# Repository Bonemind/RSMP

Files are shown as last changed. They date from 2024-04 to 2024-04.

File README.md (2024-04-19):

# RSMP

AKA "Rockstars Macropad". A [KMK](https://github.com/KMKfw/kmk_firmware) and Raspberry pi based 20 key macropad. The macropad is direct pin, meaning every button uses a dedication gpio pin, so no diodes are needed.

This was created for a workshop at [Team Rockstars IT](https://www.teamrockstars.nl/)

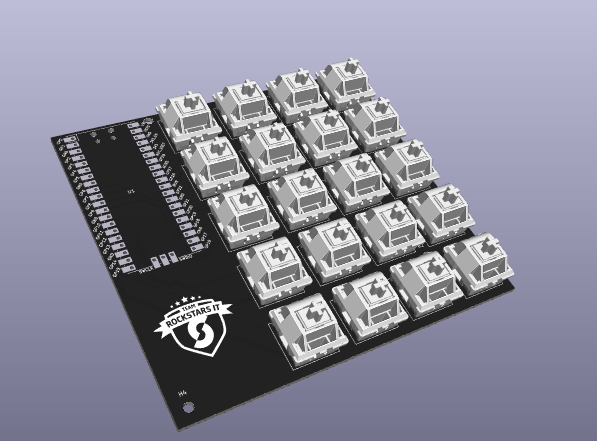
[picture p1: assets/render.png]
macropad render


## BOM

  - Raspberry Pi Pico. Make sure you get the variant with gpio pins 16/17 in the bottom right
  - 20 Cherry MX compatible switches
  - 20 Cherry MX keycaps
  - Main PCB
  - Bottom plate PCB
  - 8x M2.5 screws
  - 4 Spacers
  - Those round bumper things you stick under something to make it non-slip

## Software

  - Dowload the [Circuitpython](https://circuitpython.org/) release for the pico board.
  - Plug in the pi pico while holding the "boot" button
  - Copy the circuitpython Uf2 to the root of the device
  - It should now reboot, and you should have a "CIRCUITPY" storage device
  - Remove the `code.py` file from the storage device
  - Copy all files from the `firmware` folder to the root of the drive
  - Replug the device

It should now behave as a keyboard.

### Firmware

This macropad uses KMK for it's firmware. KMK is a flexible circuitpython based project for mechanical keyboards that offers a lot of options. The basic firmware for the RSMP is simple, in that every button outputs a letter. To customize the behavior, you can modify `main.py`.

As an example of layers, the bottom left button will output a space when tapped, and when held, the buttons will output numbers and various symbols instead of letters.

## Credits

  - [KMK](https://github.com/KMKfw/kmk_firmware) - Keyboard software
  - [ncarandini](https://github.com/ncarandini/KiCad-RP-Pico) - Kicad pi pico footprint and model
  - [foostan](https://github.com/foostan/kbd) - Keyboard switch footprints

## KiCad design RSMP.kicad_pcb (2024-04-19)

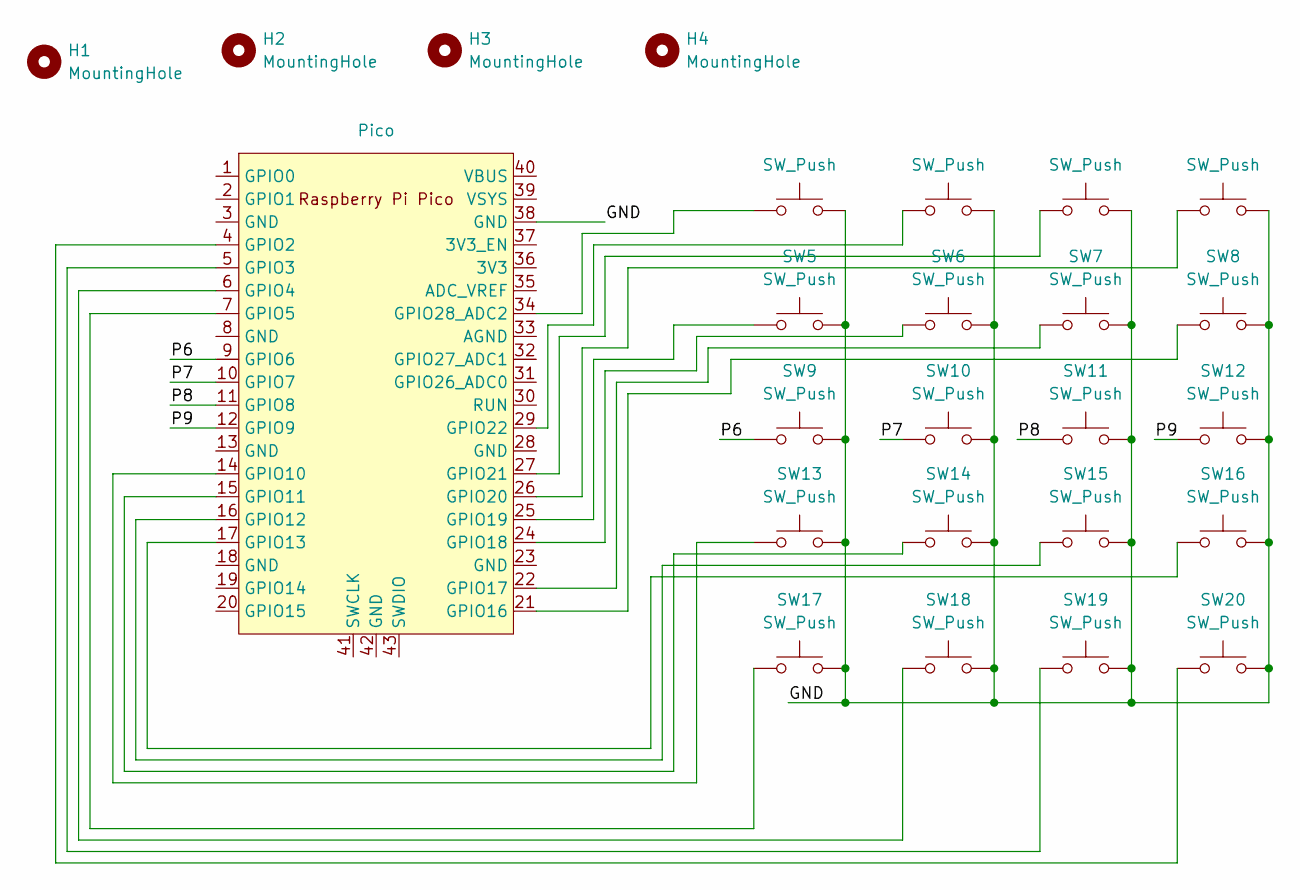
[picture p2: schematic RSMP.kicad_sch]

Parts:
H1, H2, H3, H4: MountingHole; MountingHole_2.7mm_M2.5
SW1, SW2, SW3, SW4, SW5, SW6, SW7, SW8, SW9, SW10, SW11, SW12, SW13, SW14, SW15, SW16, SW17, SW18, SW19, SW20: SW_Push; SW_Cherry_MX_1.00u_PCB
U1: Pico; RPi_Pico_SMD_TH

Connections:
/GND: SW1.2, SW2.2, SW3.2, SW4.2, SW5.2, SW6.2, SW7.2, SW8.2, SW9.2, SW10.2, SW11.2, SW12.2, SW13.2, SW14.2, SW15.2, SW16.2, SW17.2, SW18.2, SW19.2, SW20.2, U1.38 (GND)
/P6: SW9.1, U1.9 (GPIO6)
/P7: SW10.1, U1.10 (GPIO7)
/P8: SW11.1, U1.11 (GPIO8)
/P9: SW12.1, U1.12 (GPIO9)
unnamed: SW20.1, U1.4 (GPIO2)
unnamed: SW19.1, U1.5 (GPIO3)
unnamed: SW18.1, U1.6 (GPIO4)
unnamed: SW17.1, U1.7 (GPIO5)
unnamed: SW13.1, U1.14 (GPIO10)
unnamed: SW14.1, U1.15 (GPIO11)
unnamed: SW15.1, U1.16 (GPIO12)
unnamed: SW16.1, U1.17 (GPIO13)
unnamed: SW8.1, U1.21 (GPIO16)
unnamed: SW7.1, U1.22 (GPIO17)
unnamed: SW6.1, U1.24 (GPIO18)
unnamed: SW5.1, U1.25 (GPIO19)
unnamed: SW4.1, U1.26 (GPIO20)
unnamed: SW3.1, U1.27 (GPIO21)
unnamed: SW2.1, U1.29 (GPIO22)
unnamed: SW1.1, U1.34 (GPIO28_ADC2)

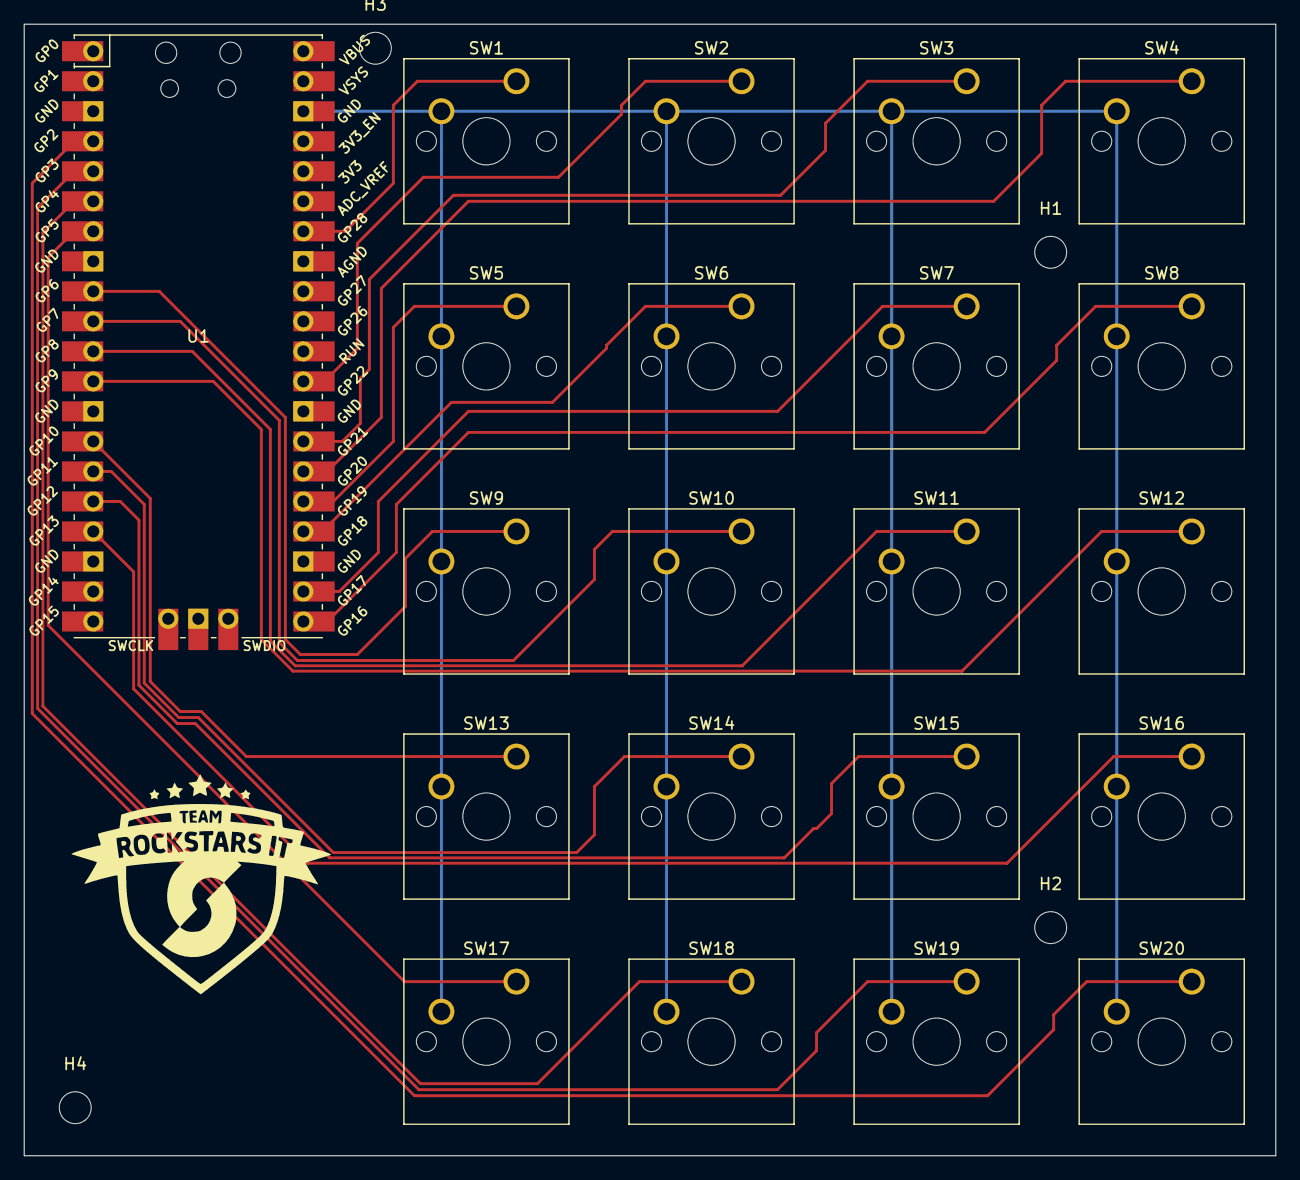
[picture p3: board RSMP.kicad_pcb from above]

Board: 2 copper layers, 105.9 x 95.8 mm, 25 parts (0 on the bottom side), 21 nets.

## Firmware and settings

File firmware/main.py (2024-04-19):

from kb import KMKKeyboard

from kmk.keys import KC
from kmk.modules.layers import Layers

keyboard = KMKKeyboard()
keyboard.tap_time = 100


layers = Layers()

layers_ext = Layers()
layers_ext.tap_time = 100

keyboard.modules = [layers_ext]
keyboard.extensions = []
#
# Cleaner key names
# _______ = KC.TRNS
# XXXXXXX = KC.NO

LAYER_ALT = 1
KCALT = KC.LT(LAYER_ALT, KC.SPC)

keyboard.keymap = [
    [  
        KC.A,    KC.B,    KC.C,    KC.D,
        KC.E,    KC.F,    KC.J,    KC.K,
        KC.L,    KC.M,    KC.N,    KC.O,
        KC.P,    KC.Q,    KC.R,    KC.S,
        KCALT,    KC.U,    KC.V,    KC.W,
    ],
    [  
        KC.N1,       KC.N2,       KC.N3,       KC.N4,
        KC.N5,       KC.N6,       KC.N7,       KC.N8,
        KC.N9,       KC.N0,       KC.LBRACKET, KC.RBRACKET,
        KC.QUOTE,    KC.COMMA,    KC.GRAVE,    KC.DOT,
        KC.SLASH,    KC.MINUS,    KC.EQUAL,    KC.ENTER,
    ],
]

if __name__ == '__main__':
    keyboard.go()

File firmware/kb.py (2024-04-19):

import board
import digitalio

from storage import getmount

from kmk.kmk_keyboard import KMKKeyboard as _KMKKeyboard
from kmk.scanners.keypad import KeysScanner

# GPIO to key mapping, Left
KEY_CFG = [
    board.GP28, board.GP22, board.GP21, board.GP20,
    board.GP19, board.GP18, board.GP17, board.GP16,
    board.GP6,  board.GP7,  board.GP8,  board.GP9,
    board.GP10, board.GP11, board.GP12, board.GP13,
    board.GP5,  board.GP4,  board.GP3,  board.GP2,
]

class KMKKeyboard(_KMKKeyboard):
    def __init__(self):
        # create and register the scanner
        self.matrix = KeysScanner(
            pins = KEY_CFG,
            value_when_pressed = False,	
            pull=True,
        )

    # flake8: noqa
    # fmt: off
    # coord_mapping = [
    #  0,  1,  2,  3,  4,  5,   21, 22, 23, 24, 25, 26,
    #  6,  7,  8,  9, 10, 11,   27, 28, 29, 30, 31, 32,
    # 12, 13, 14, 15, 16, 17,   33, 34, 35, 36, 37, 38,
    #             18, 19, 20,   39, 40, 41
    # ]
